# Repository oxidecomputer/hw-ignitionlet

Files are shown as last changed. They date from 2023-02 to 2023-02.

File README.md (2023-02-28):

# hw-ignitionlet
Breakout board for the ice40 FPGA with SPI PMOD interface

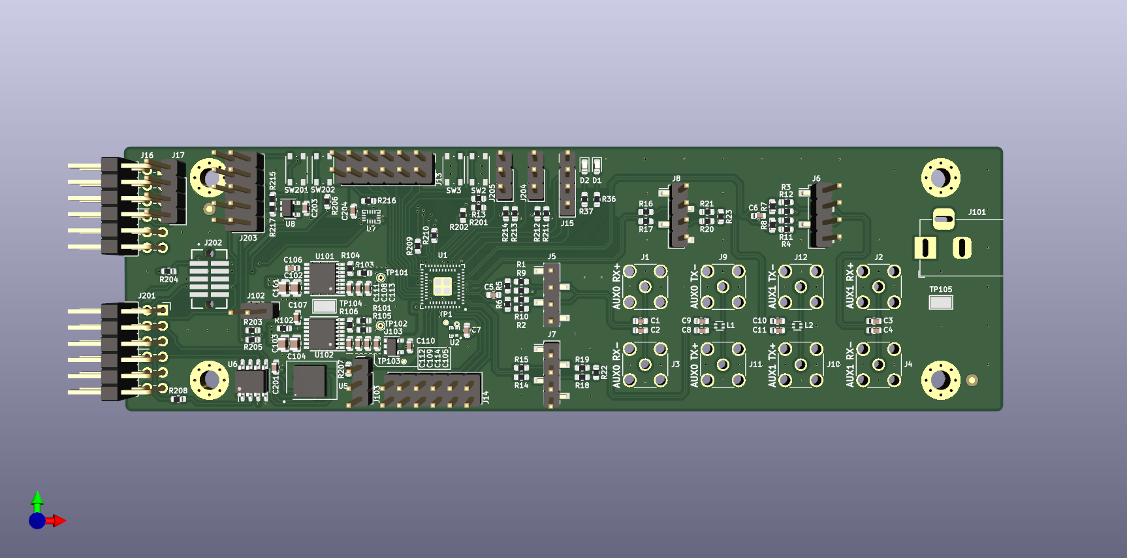
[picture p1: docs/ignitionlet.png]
ignitionlet


# Bonus boards
There is a lvds_sma_adaptor included which breaks out the LVDS pairs
with a compatible pinout to the [Lattice ECP5 Dev Kit](https://www.latticesemi.com/products/developmentboardsandkits/ecp5evaluationboard)

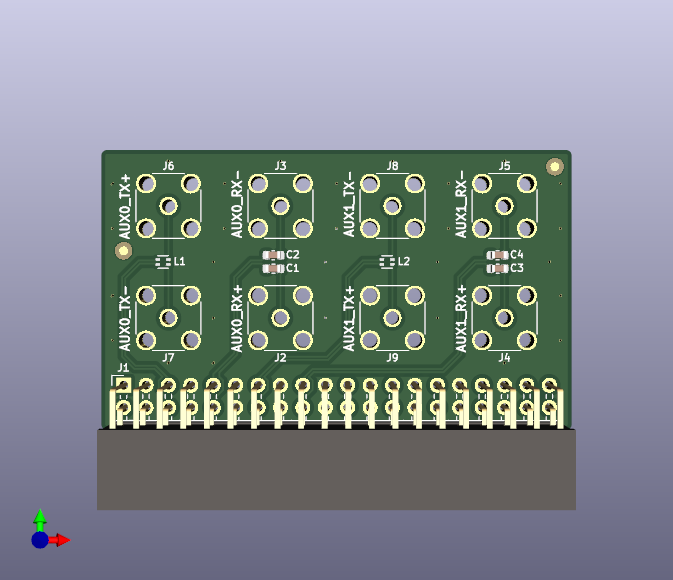
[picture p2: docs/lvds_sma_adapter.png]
lvds_board


# Status
No known required rework. See schematic notes for required
jumper settings.

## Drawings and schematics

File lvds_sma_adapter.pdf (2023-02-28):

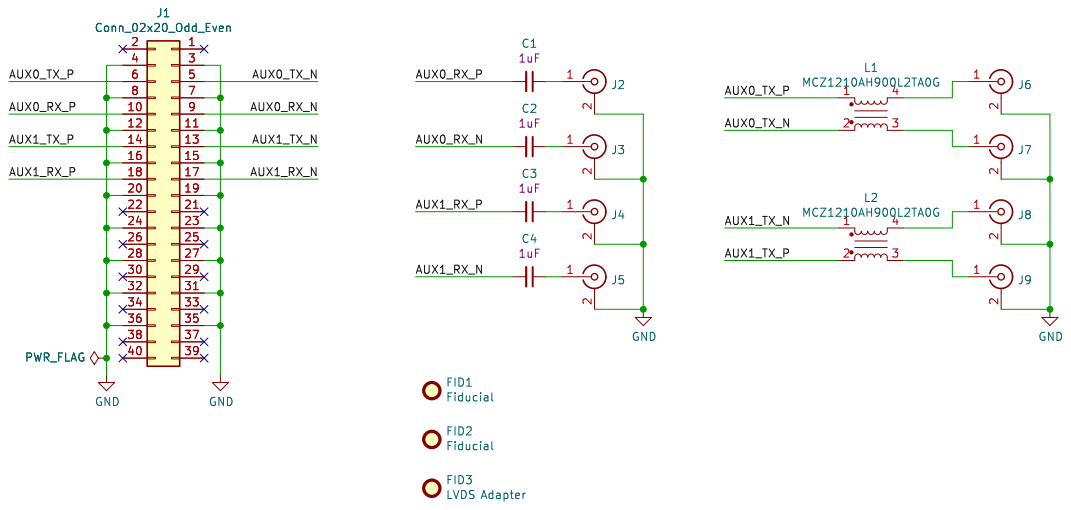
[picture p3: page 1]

Id: 1/1 Title: LVDS SMA Adapter File: lvds_sma_adapter.kicad_sch Sheet: / Oxide Computer Co. C3

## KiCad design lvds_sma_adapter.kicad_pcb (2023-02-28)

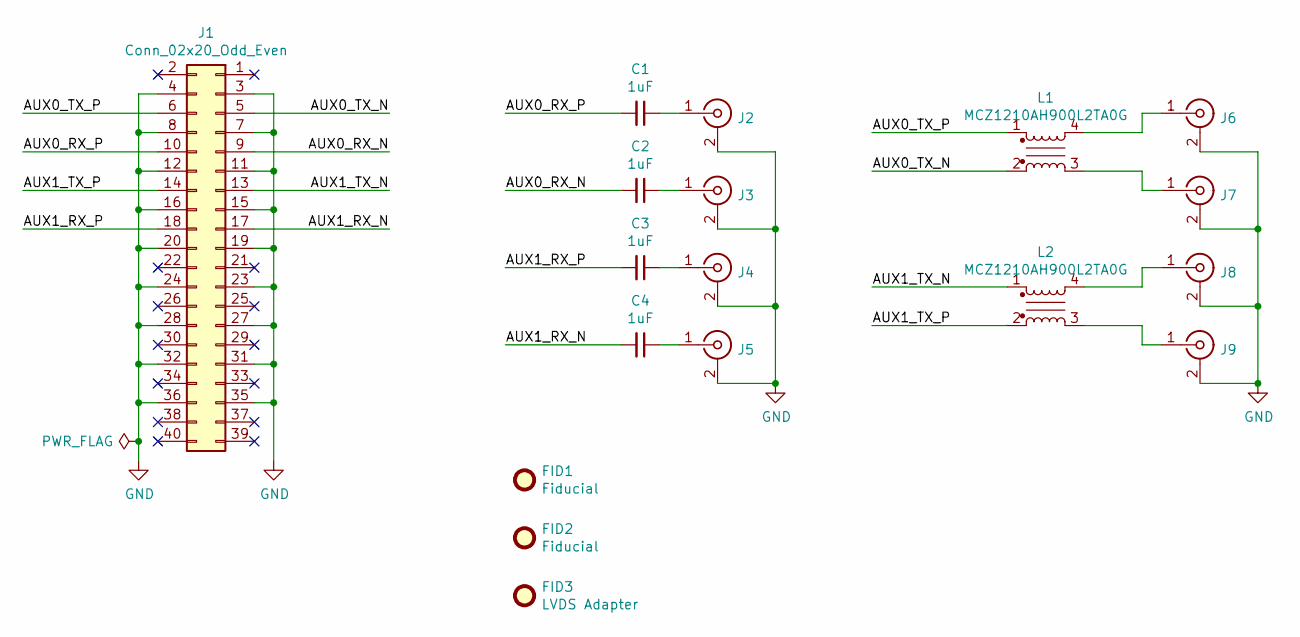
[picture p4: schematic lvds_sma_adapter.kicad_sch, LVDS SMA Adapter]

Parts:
C1, C2, C3, C4: GCM188R71E105KA64D; C_0603_1608Metric
FID1, FID2: Fiducial; Fiducial_1mm_Mask2mm
FID3: LVDS Adapter; Oxide_Board_Identifier_23x6mm
J1: Conn_02x20_Odd_Even; PinSocket_2x20_P2.54mm_Horizontal
J2, J3, J4, J5, J6, J7, J8, J9: Conn_Coaxial; SMA_Amphenol_132134-16_Vertical
L1, L2: MCZ1210AH900L2TA0G; L_Choke_MCZ1210AH

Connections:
/AUX0_RX_N: C2.2, J1.9
/AUX0_RX_P: C1.2, J1.10
/AUX0_TX_N: J1.5, L1.2
/AUX0_TX_P: J1.6, L1.1
/AUX1_RX_N: C4.2, J1.17
/AUX1_RX_P: C3.2, J1.18
/AUX1_TX_N: J1.13, L2.1
/AUX1_TX_P: J1.14, L2.2
GND: J1.3, J1.4, J1.7, J1.8, J1.11, J1.12, J1.15, J1.16, J1.19, J1.20, J1.23, J1.24, J1.27, J1.28, J1.31, J1.32, J1.35, J1.36, J2.2 (Ext), J3.2 (Ext), J4.2 (Ext), J5.2 (Ext), J6.2 (Ext), J7.2 (Ext), J8.2 (Ext), J9.2 (Ext)
unnamed: C1.1, J2.1 (In)
unnamed: C2.1, J3.1 (In)
unnamed: C3.1, J4.1 (In)
unnamed: C4.1, J5.1 (In)
unnamed: J6.1 (In), L1.4
unnamed: J7.1 (In), L1.3
unnamed: J8.1 (In), L2.4
unnamed: J9.1 (In), L2.3

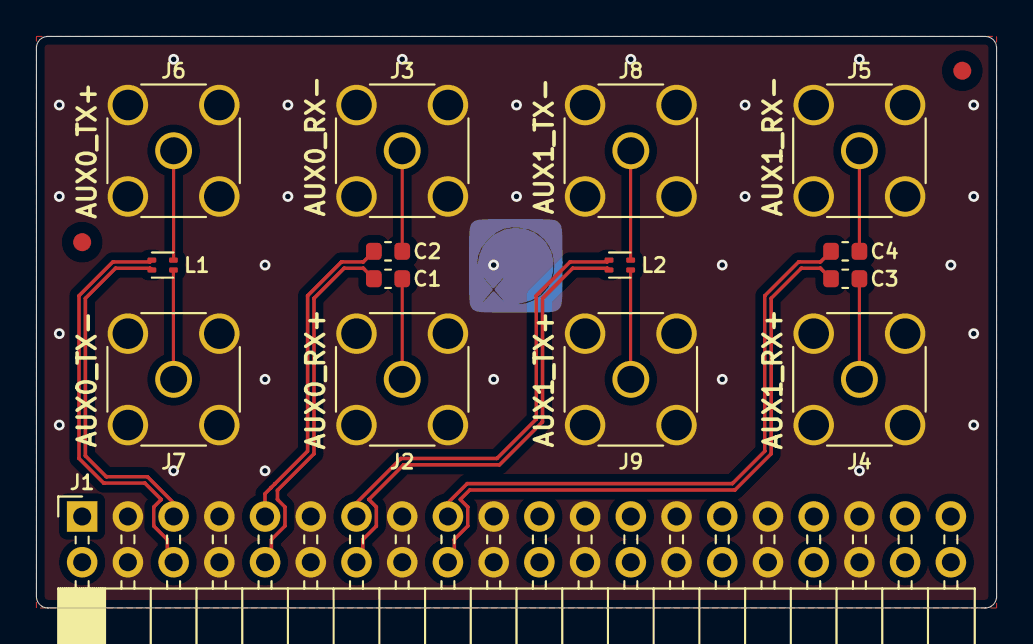
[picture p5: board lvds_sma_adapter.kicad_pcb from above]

Board: 4 copper layers, 53.3 x 31.8 mm, 18 parts (1 on the bottom side), 17 nets.

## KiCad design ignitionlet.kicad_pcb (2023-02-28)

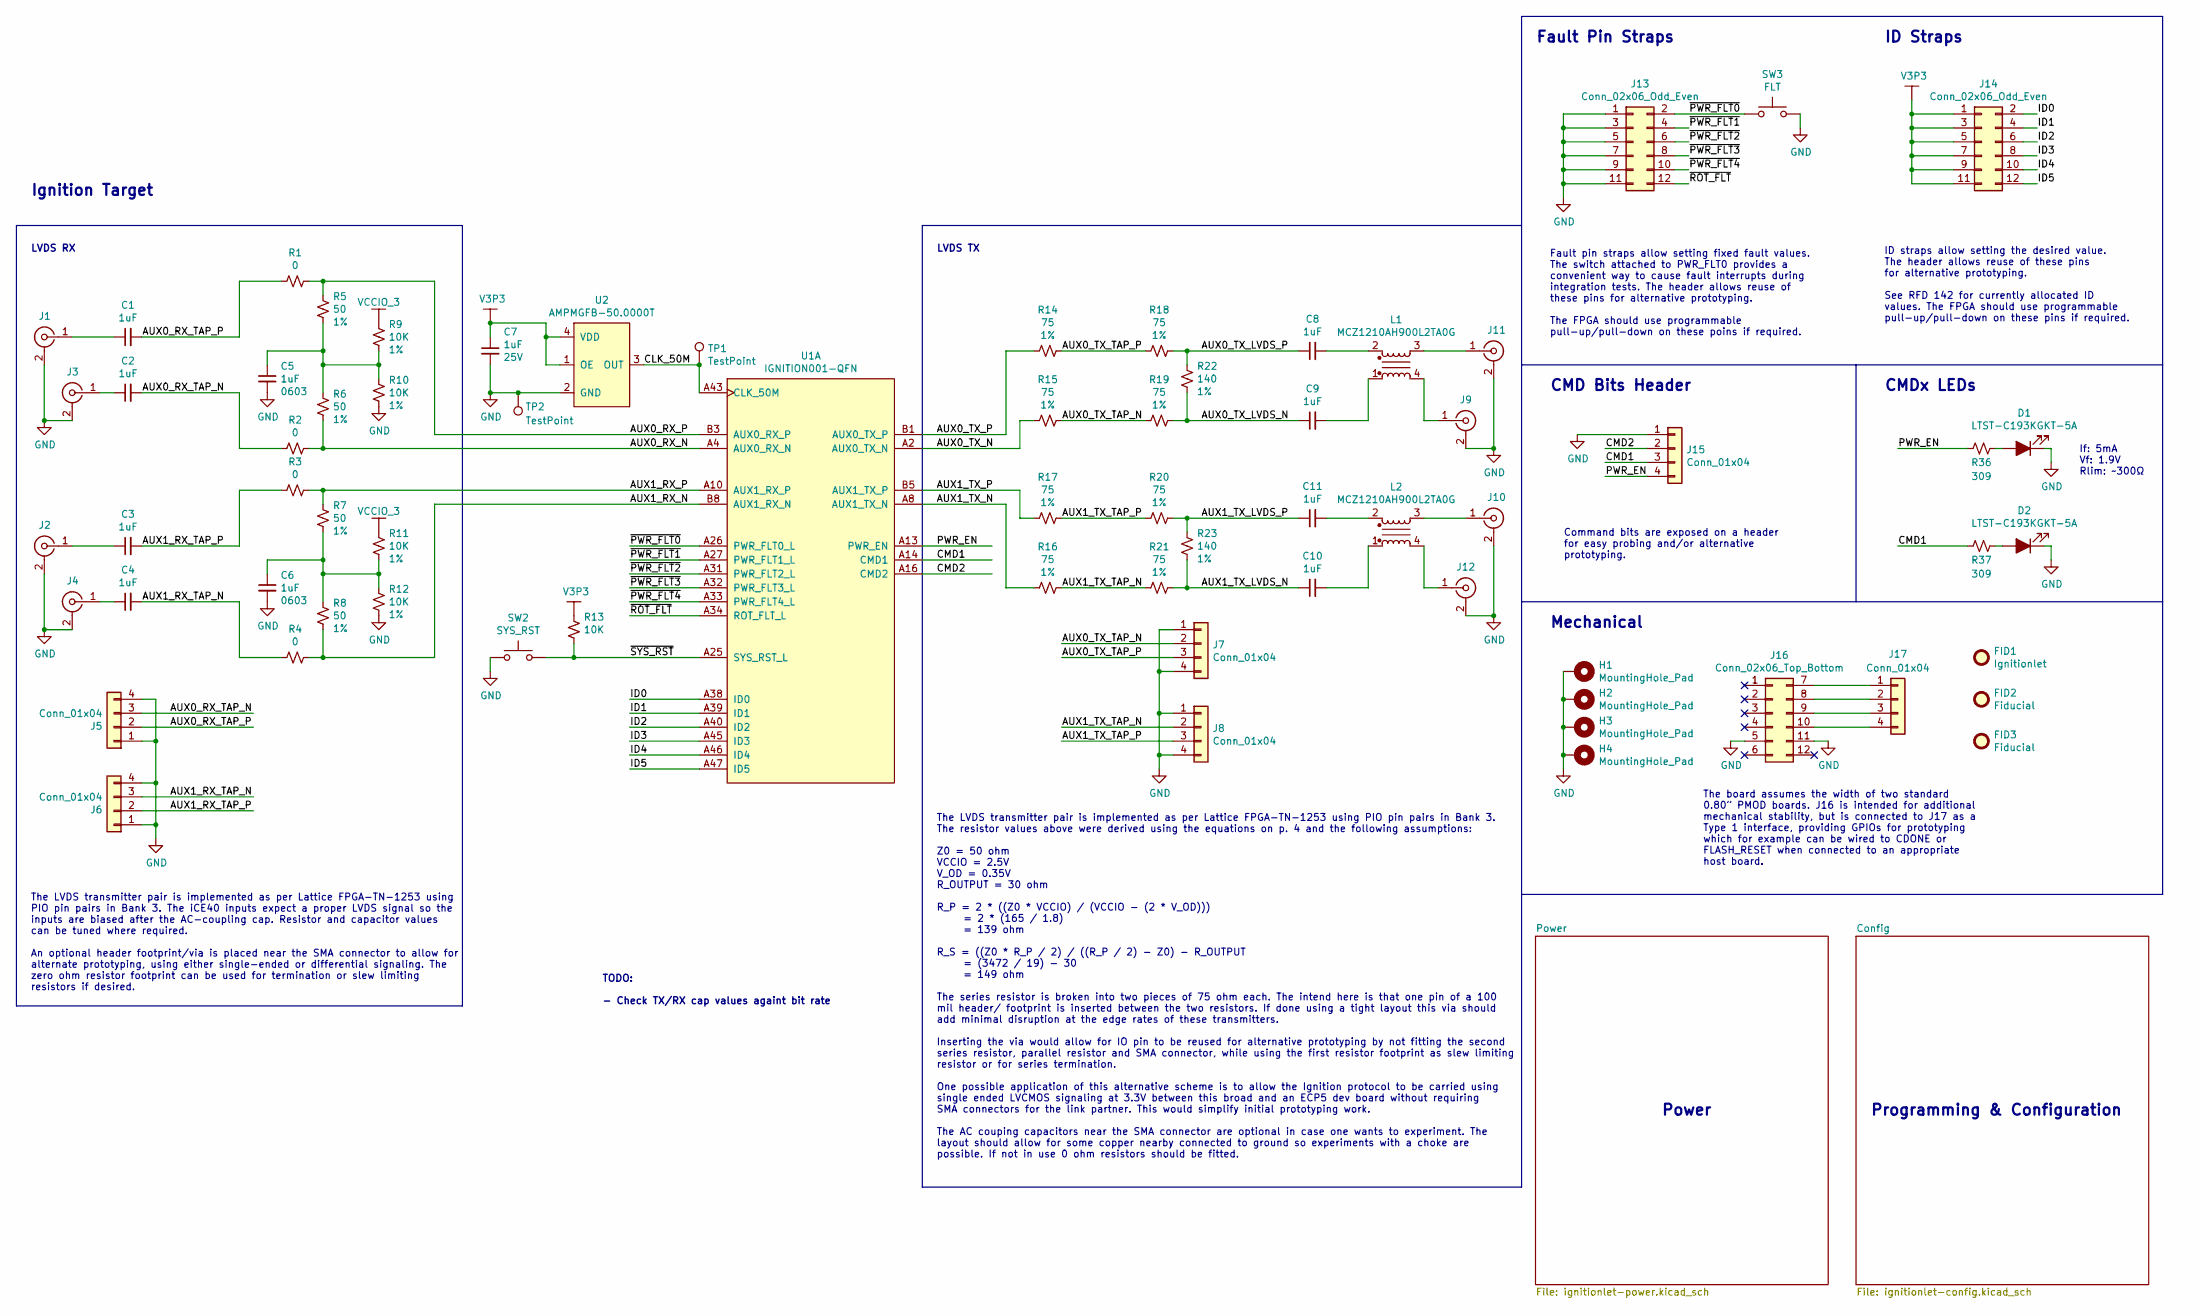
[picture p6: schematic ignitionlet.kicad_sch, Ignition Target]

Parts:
C1, C2, C3, C4, C5, C6, C7, C8, C9, C10, C11: GCM188R71E105KA64D; C_0603_1608Metric
D1, D2: LTST-C193KGKT-5A; LED_0603_1608Metric
FID1: Ignitionlet; Oxide_Board_Identifier_23x6mm_PCBWay
FID2, FID3: Fiducial; Fiducial_1mm_Mask2mm
H1, H2, H3, H4: MountingHole_Pad; MountingHole_3.2mm_M3_Pad_Via
J1, J2, J3, J4, J9, J10, J11, J12: Conn_Coaxial; SMA_Amphenol_132134-16_Vertical
J5, J6, J7, J8: Conn_01x04; PinHeader_1x04_P2.54mm_Vertical_SMD_Pin1Left
J13, J14: Conn_02x06_Odd_Even; PinHeader_2x06_P2.54mm_Vertical
J15, J17: Conn_01x04; PinHeader_1x04_P2.54mm_Vertical
J16: Conn_02x06_Top_Bottom; PMOD_12pin_peripheral_horizontal
L1, L2: MCZ1210AH900L2TA0G; L_Choke_MCZ1210AH
R1, R2, R3, R4: 0; R_0603_1608Metric; Tolerance 1%
R5, R6, R7, R8: 50; R_0603_1608Metric; Tolerance 1%
R9, R10, R11, R12, R13: 10K; R_0603_1608Metric; Tolerance 1%
R14, R15, R16, R17, R18, R19, R20, R21: 75; R_0603_1608Metric; Tolerance 1%
R22, R23: 140; R_0603_1608Metric; Tolerance 1%
R36, R37: 309; R_0603_1608Metric; Tolerance 1%
SW2: SYS_RST; PTS815
SW3: FLT; PTS815
TP1: TestPoint; TestPoint_Pad_D0.6mm
TP2: TestPoint; TestPoint_THTPad_D0.6mm_Drill0.3mm
U1: IGNITION001-QFN; Lattice_DRQFN-84-1EP_7x7mm_P0.50mm_EP3.5x3.5mm_ThermalVias
U2: AMPMGFB-50.0000T; ABRACON_VFLGA-4_1.6x1.2mm

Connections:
/AUX0_RX_N: R2.1, R6.2, U1.A4 (AUX0_RX_N)
/AUX0_RX_P: R1.1, R5.1, U1.B3 (AUX0_RX_P)
/AUX0_RX_TAP_N: C2.2, J5.3, R2.2
/AUX0_RX_TAP_P: C1.2, J5.2, R1.2
/AUX0_TX_LVDS_N: C9.1, R19.1, R22.1
/AUX0_TX_LVDS_P: C8.1, R18.1, R22.2
/AUX0_TX_N: R15.2, U1.A2 (AUX0_TX_N)
/AUX0_TX_P: R14.2, U1.B1 (AUX0_TX_P)
/AUX0_TX_TAP_N: J7.2, R15.1, R19.2
/AUX0_TX_TAP_P: J7.3, R14.1, R18.2
/AUX1_RX_N: R4.1, R8.2, U1.B8 (AUX1_RX_N)
/AUX1_RX_P: R3.1, R7.1, U1.A10 (AUX1_RX_P)
/AUX1_RX_TAP_N: C4.2, J6.3, R4.2
/AUX1_RX_TAP_P: C3.2, J6.2, R3.2
/AUX1_TX_LVDS_N: C10.1, R21.1, R23.1
/AUX1_TX_LVDS_P: C11.1, R20.1, R23.2
/AUX1_TX_N: R16.2, U1.A8 (AUX1_TX_N)
/AUX1_TX_P: R17.2, U1.B5 (AUX1_TX_P)
/AUX1_TX_TAP_N: J8.2, R16.1, R21.2
/AUX1_TX_TAP_P: J8.3, R17.1, R20.2
/CLK_50M: TP1.1, U1.A43 (CLK_50M), U2.3 (OUT)
/CMD1: J15.3, R37.2, U1.A14 (CMD1)
/CMD2: J15.2, U1.A16 (CMD2)
/ID0: J14.2, U1.A38 (ID0)
/ID1: J14.4, U1.A39 (ID1)
/ID2: J14.6, U1.A40 (ID2)
/ID3: J14.8, U1.A45 (ID3)
/ID4: J14.10, U1.A46 (ID4)
/ID5: J14.12, U1.A47 (ID5)
/PWR_EN: J15.4, R36.2, U1.A13 (PWR_EN)
/~PWR_FLT0: J13.2, SW3.1, U1.A26 (PWR_FLT0_L)
/~PWR_FLT1: J13.4, U1.A27 (PWR_FLT1_L)
/~PWR_FLT2: J13.6, U1.A31 (PWR_FLT2_L)
/~PWR_FLT3: J13.8, U1.A32 (PWR_FLT3_L)
/~PWR_FLT4: J13.10, U1.A33 (PWR_FLT4_L)
/~ROT_FLT: J13.12, U1.A34 (ROT_FLT_L)
/~SYS_RST: R13.2, SW2.2, U1.A25 (SYS_RST_L)
GND: C5.2, C6.2, C7.2, D1.1 (K), D2.1 (K), H1.1, H2.1, H3.1, H4.1, J1.2 (Ext), J2.2 (Ext), J3.2 (Ext), J4.2 (Ext), J5.1, J5.4, J6.1, J6.4, J7.1, J7.4, J8.1, J8.4, J9.2 (Ext), J10.2 (Ext), J11.2 (Ext), J12.2 (Ext), J13.1, J13.3, J13.5, J13.7, J13.9, J13.11, J15.1, J16.5, J16.11, R10.2, R12.2, SW2.1, SW3.2, TP2.1, U2.2 (GND); also elsewhere on the board
unnamed: C1.1, J1.1 (In)
unnamed: C2.1, J3.1 (In)
unnamed: C3.1, J2.1 (In)
unnamed: C4.1, J4.1 (In)
unnamed: C5.1, R5.2, R6.1, R9.2, R10.1
unnamed: C6.1, R7.2, R8.1, R11.2, R12.1
unnamed: C8.2, L1.2
unnamed: C9.2, L1.1
unnamed: C10.2, L2.1
unnamed: C11.2, L2.2
unnamed: D1.2 (A), R36.1
unnamed: D2.2 (A), R37.1
unnamed: J9.1 (In), L1.4
unnamed: J10.1 (In), L2.3
unnamed: J11.1 (In), L1.3
unnamed: J12.1 (In), L2.4
unnamed: J16.7, J17.1
unnamed: J16.8, J17.2
unnamed: J16.9, J17.3
unnamed: J16.10, J17.4
V3P3: C7.1, J14.1, J14.3, J14.5, J14.7, J14.9, J14.11, R13.1, U2.1 (OE), U2.4 (VDD); also elsewhere on the board
VCCIO_3: R9.1, R11.1; also elsewhere on the board

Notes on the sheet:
CMDx LEDs
The board assumes the width of two standard 0.80” PMOD boards. J16 is intended for additional mechanical stability, but is connected to J17 as a Type 1 interface, providing GPIOs for prototyping which for example can be wired to CDONE or FLASH_RESET when connected to an appropriate host board.
LVDS TX
Ignition Target
Mechanical
Fault Pin Straps
Command bits are exposed on a header for easy probing and/or alternative prototyping.
The LVDS transmitter pair is implemented as per Lattice FPGA-TN-1253 using PIO pin pairs in Bank 3. The resistor values above were derived using the equations on p. 4 and the following assumptions: Z0 = 50 ohm VCCIO = 2.5V V_OD = 0.35V R_OUTPUT = 30 ohm R_P = 2 * ((Z0 * VCCIO) / (VCCIO - (2 * V_OD)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
LVDS RX
ID Straps
CMD Bits Header
Fault pin straps allow setting fixed fault values. The switch attached to PWR_FLT0 provides a convenient way to cause fault interrupts during integration tests. The header allows reuse of these pins for alternative prototyping. The FPGA should use programmable pull-up/pull-down on these poins if re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
Programming & Configuration
The LVDS transmitter pair is implemented as per Lattice FPGA-TN-1253 using PIO pin pairs in Bank 3. The iCE40 inputs expect a proper LVDS signal so the inputs are biased after the AC-coupling cap. Resistor and capacitor values can be tuned where required. An optional header footprint/via is placed 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
ID straps allow setting the desired value. The header allows reuse of these pins for alternative prototyping. See RFD 142 for currently allocated ID values. The FPGA should use programmable pull-up/pull-down on these pins if required.
If: 5mA Vf: 1.9V Rlim: ~300Ω
Power
TODO: - Check TX/RX cap values againt bit rate

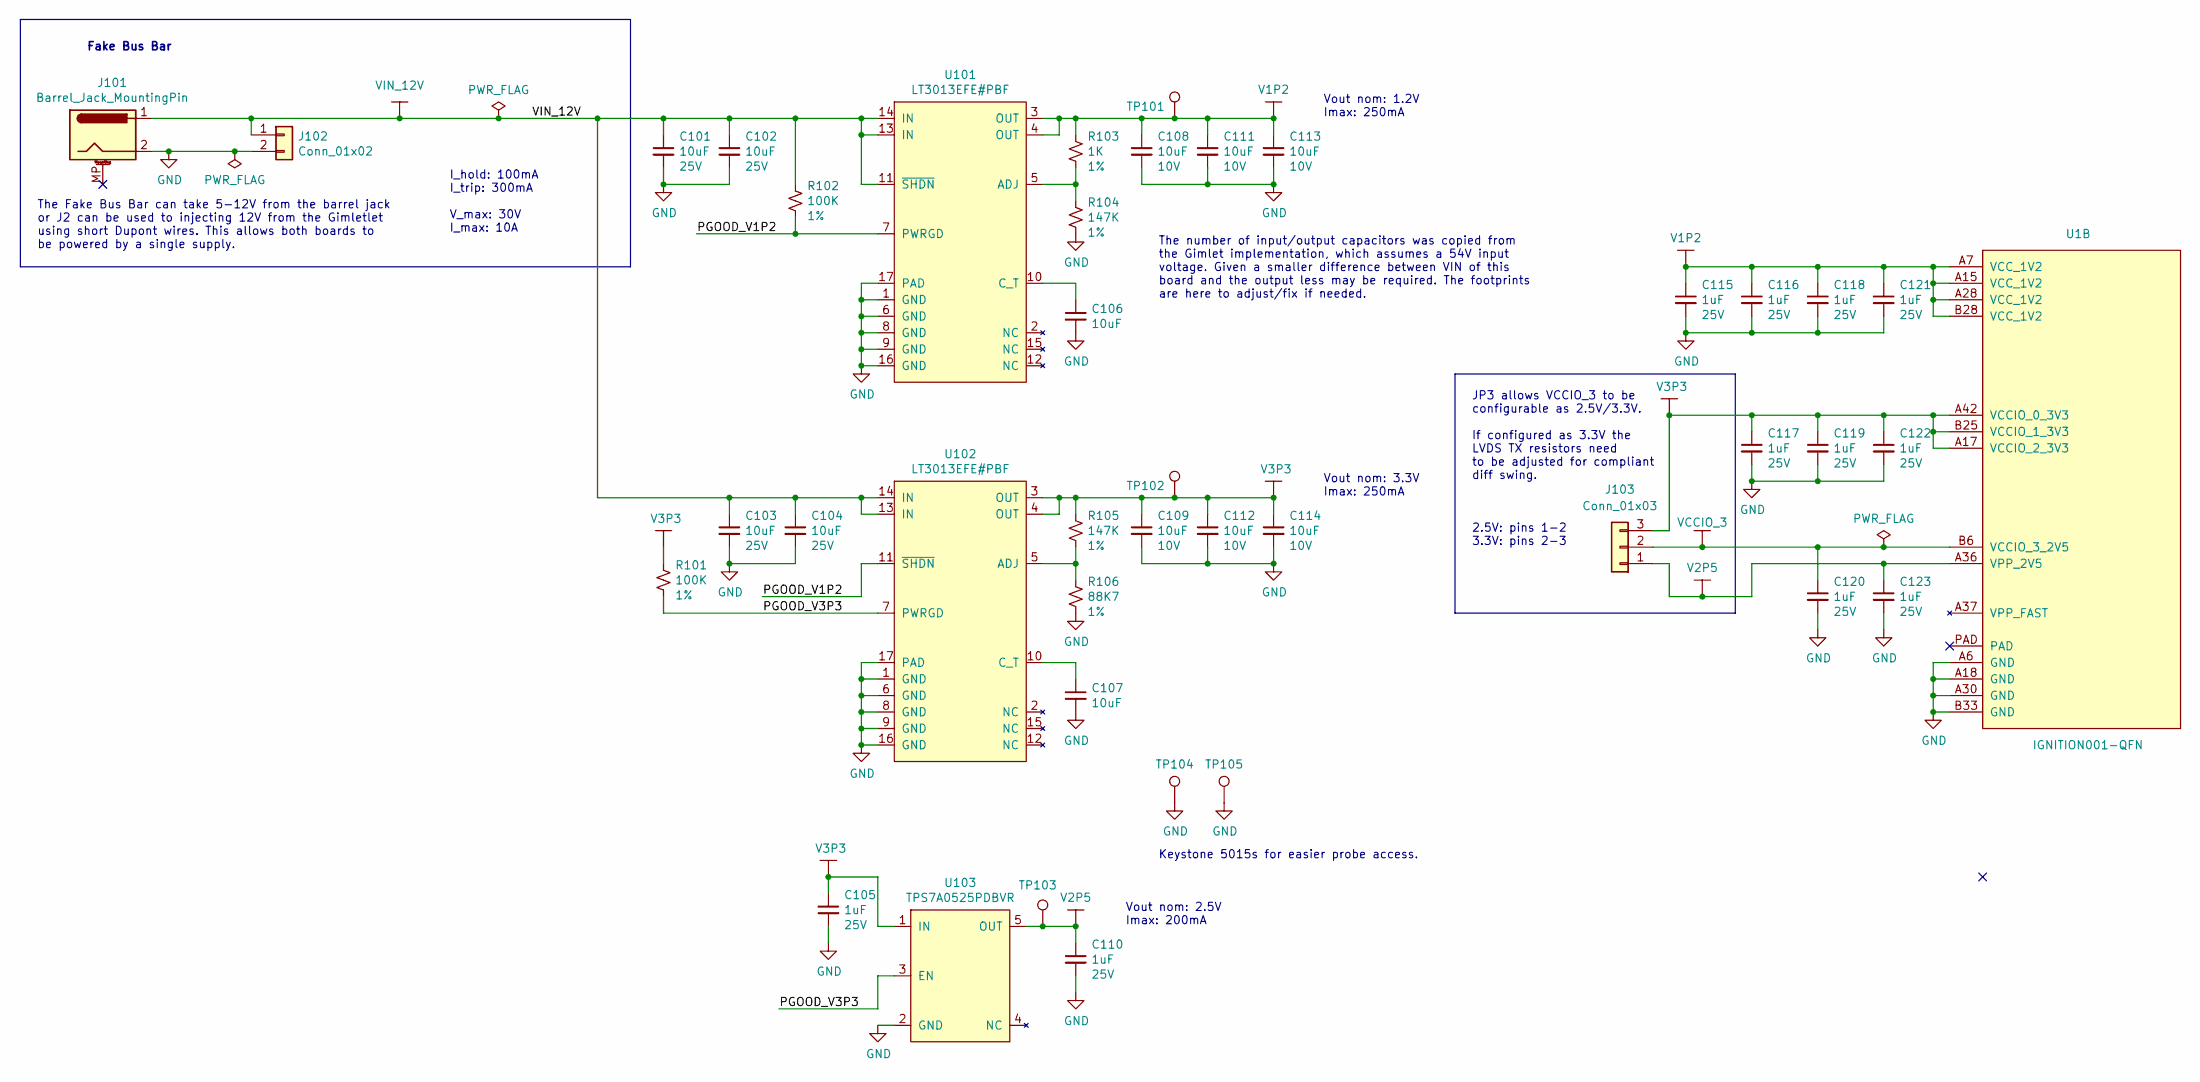
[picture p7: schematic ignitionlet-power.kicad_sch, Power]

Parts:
C101, C102, C103, C104: GRM21BR61E106KA73K; C_0805_2012Metric; Voltage 25V
C105, C110, C115, C116, C117, C118, C119, C120, C121, C122, C123: GCM188R71E105KA64D; C_0603_1608Metric
C106, C107: C0603C106M8PACTU; C_0603_1608Metric
C108, C109, C111, C112, C113, C114: C0603C106M8PACTU; C_0603_1608Metric; Voltage 10V
J101: Barrel_Jack_MountingPin; BarrelJack_Horizontal
J102: Conn_01x02; PinHeader_1x02_P2.54mm_Vertical
J103: Conn_01x03; PinHeader_1x03_P2.54mm_Vertical
R101, R102: 100K; R_0603_1608Metric; Tolerance 1%
R103: 1K; R_0603_1608Metric; Tolerance 1%
R104, R105: 147K; R_0603_1608Metric; Tolerance 1%
R106: 88K7; R_0603_1608Metric; Tolerance 1%
TP101, TP102: TestPoint; TestPoint_THTPad_D1.0mm_Drill0.5mm
TP103: TestPoint; TestPoint_Pad_D0.6mm
TP104, TP105: TestPoint; TestPoint_Keystone_5015_Micro-Minature
U1: IGNITION001-QFN
U101, U102: LT3013EFE#PBF; TSSOP-16-1EP_4.4x5mm_P0.65mm
U103: TPS7A0525PDBVR; SOT-23-5

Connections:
/Power/PGOOD_V1P2: R102.2, U101.7 (PWRGD), U102.11 (~SHDN)
/Power/PGOOD_V3P3: R101.2, U102.7 (PWRGD), U103.3 (EN)
GND: C101.2, C102.2, C103.2, C104.2, C105.2, C106.2, C107.2, C108.2, C109.2, C110.2, C111.2, C112.2, C113.2, C114.2, C115.2, C116.2, C117.2, C118.2, C119.2, C120.2, C121.2, C122.2, C123.2, J101.2, J102.2, R104.2, R106.2, TP104.1, TP105.1, U1.A6 (GND), U1.A18 (GND), U1.A30 (GND), U1.B33 (GND), U101.1 (GND), U101.6 (GND), U101.8 (GND), U101.9 (GND), U101.16 (GND), U101.17 (PAD), U102.1 (GND), U102.6 (GND), U102.8 (GND), U102.9 (GND), U102.16 (GND), U102.17 (PAD), U103.2 (GND); also elsewhere on the board
unnamed: C106.1, U101.10 (C_T)
unnamed: C107.1, U102.10 (C_T)
unnamed: R103.2, R104.1, U101.5 (ADJ)
unnamed: R105.2, R106.1, U102.5 (ADJ)
V1P2: C108.1, C111.1, C113.1, C115.1, C116.1, C118.1, C121.1, R103.1, TP101.1, U1.A7 (VCC_1V2), U1.A15 (VCC_1V2), U1.A28 (VCC_1V2), U1.B28 (VCC_1V2), U101.3 (OUT), U101.4 (OUT)
V2P5: C110.1, C123.1, J103.1, TP103.1, U1.A36 (VPP_2V5), U103.5 (OUT)
V3P3: C105.1, C109.1, C112.1, C114.1, C117.1, C119.1, C122.1, J103.3, R101.1, R105.1, TP102.1, U1.A17 (VCCIO_2_3V3), U1.A42 (VCCIO_0_3V3), U1.B25 (VCCIO_1_3V3), U102.3 (OUT), U102.4 (OUT), U103.1 (IN); also elsewhere on the board
VCCIO_3: C120.1, J103.2, U1.B6 (VCCIO_3_2V5); also elsewhere on the board
VIN_12V: C101.1, C102.1, C103.1, C104.1, J101.1, J102.1, R102.1, U101.11 (~SHDN), U101.13 (IN), U101.14 (IN), U102.13 (IN), U102.14 (IN)

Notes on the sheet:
Vout nom: 2.5V Imax: 200mA
Fake Bus Bar
The Fake Bus Bar can take 5-12V from the barrel jack or J2 can be used to injecting 12V from the Gimletlet using short Dupont wires. This allows both boards to be powered by a single supply.
Keystone 5015s for easier probe access.
I_hold: 100mA I_trip: 300mA V_max: 30V I_max: 10A
The number of input/output capacitors was copied from the Gimlet implementation, which assumes a 54V input voltage. Given a smaller difference between VIN of this board and the output less may be required. The footprints are here to adjust/fix if needed.
2.5V: pins 1-2 3.3V: pins 2-3
Vout nom: 1.2V Imax: 250mA
JP3 allows VCCIO_3 to be configurable as 2.5V/3.3V. If configured as 3.3V the LVDS TX resistors need to be adjusted for compliant diff swing.
Vout nom: 3.3V Imax: 250mA

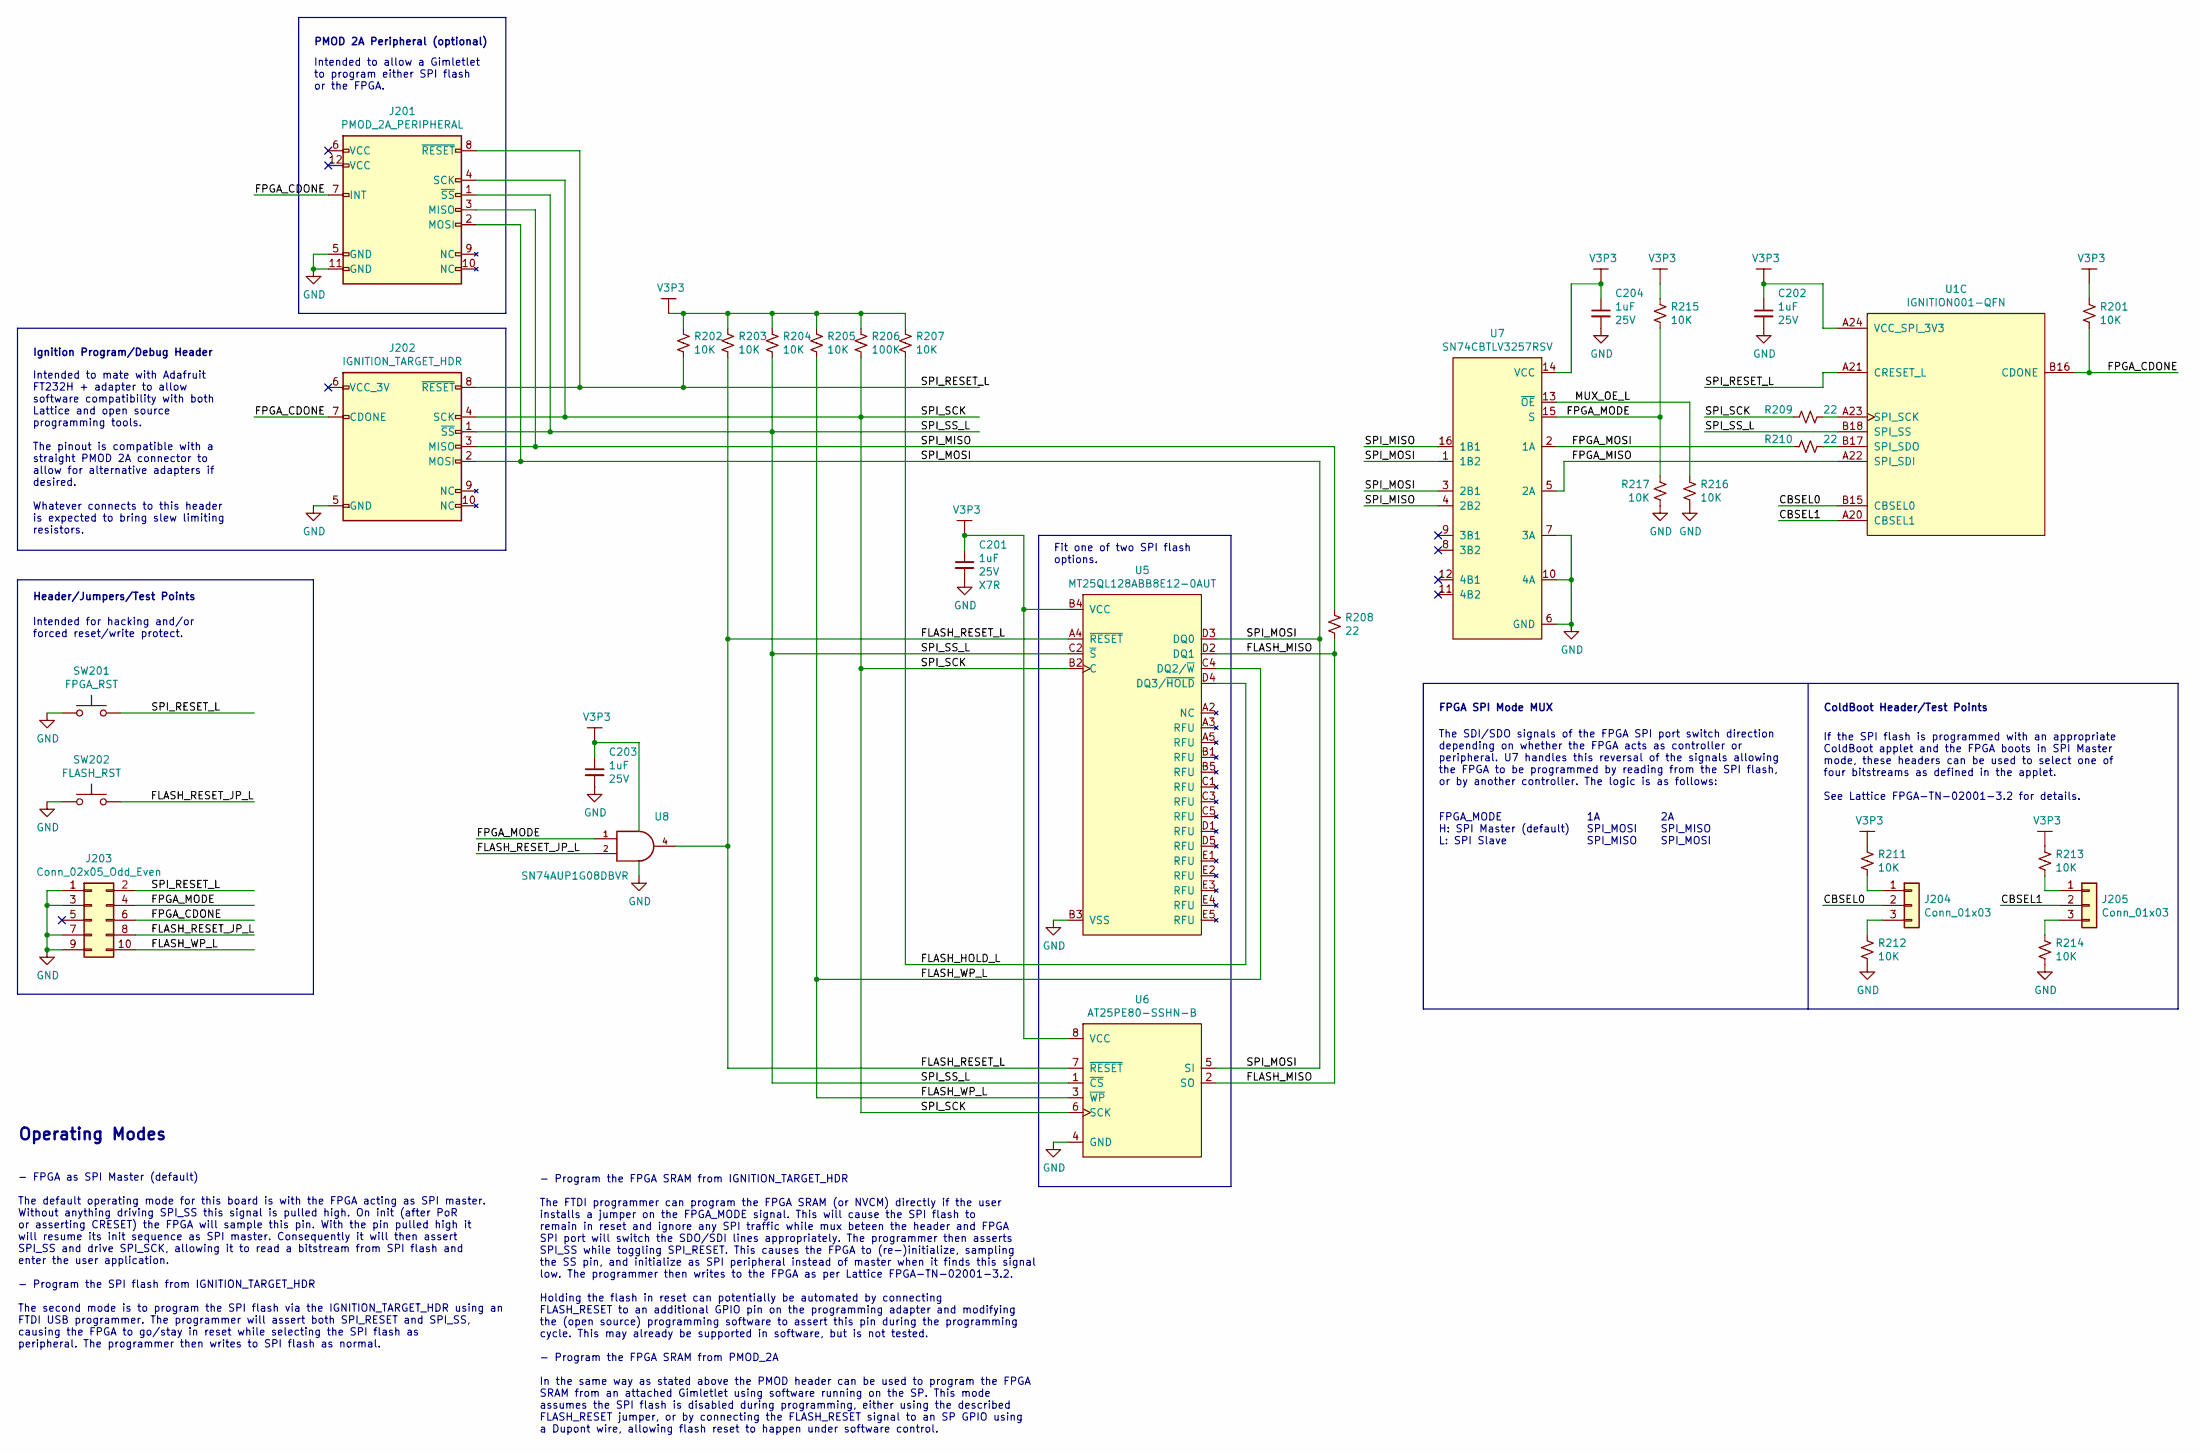
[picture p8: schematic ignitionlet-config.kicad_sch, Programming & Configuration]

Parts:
C201, C202, C203, C204: GCM188R71E105KA64D; C_0603_1608Metric
J201: PMOD_2A_PERIPHERAL; PMOD_12pin_peripheral_horizontal
J202: IGNITION_TARGET_HDR; TFC-105-02-F-D-A-K
J203: Conn_02x05_Odd_Even; PinHeader_2x05_P2.54mm_Vertical
J204, J205: Conn_01x03; PinHeader_1x03_P2.54mm_Vertical
R201, R202, R203, R204, R205, R207, R211, R212, R213, R214, R215, R216, R217: 10K; R_0603_1608Metric; Tolerance 1%
R206: 100K; R_0603_1608Metric; Tolerance 1%
R208, R209, R210: 22; R_0603_1608Metric; Tolerance 1%
SW201: FPGA_RST; PTS815
SW202: FLASH_RST; PTS815
U1: IGNITION001-QFN
U5: MT25QL128ABB8E12-0AUT; T-PBGA-24_6x8mm_Layout5x5_P1.0mm
U6: AT25PE80-SSHN-B; SOIC-8_3.9x4.9mm_P1.27mm
U7: SN74CBTLV3257RSV; Texas_RSV_S-UQFN-16_2.4x1.6mm
U8: SN74AUP1G08DBVR; SOT-23-5

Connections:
/Config/CBSEL0: J204.2, U1.B15 (CBSEL0)
/Config/CBSEL1: J205.2, U1.A20 (CBSEL1)
/Config/FLASH_HOLD_L: R207.1, U5.D4 (DQ3/~HOLD)
/Config/FLASH_MISO: R208.1, U5.D2 (DQ1), U6.2 (SO)
/Config/FLASH_RESET_JP_L: J203.8, SW202.2, U8.2
/Config/FLASH_RESET_L: R203.1, U5.A4 (~RESET), U6.7 (~RESET), U8.4
/Config/FLASH_WP_L: J203.10, R205.1, U5.C4 (DQ2/~W), U6.3 (~WP)
/Config/FPGA_CDONE: J201.7 (INT), J202.7 (CDONE), J203.6, R201.1, U1.B16 (CDONE)
/Config/FPGA_MISO: U1.A22 (SPI_SDI), U7.5 (2A)
/Config/FPGA_MODE: J203.4, R215.1, R217.2, U7.15 (S), U8.1
/Config/FPGA_MOSI: R210.2, U7.2 (1A)
/Config/MUX_OE_L: R216.2, U7.13 (~OE)
/Config/SPI_MISO: J201.3 (MISO), J202.3 (MISO), R208.2, U7.4 (2B2), U7.16 (1B1)
/Config/SPI_MOSI: J201.2 (MOSI), J202.2 (MOSI), U5.D3 (DQ0), U6.5 (SI), U7.1 (1B2), U7.3 (2B1)
/Config/SPI_RESET_L: J201.8 (~RESET), J202.8 (~RESET), J203.2, R202.1, SW201.2, U1.A21 (CRESET_L)
/Config/SPI_SCK: J201.4 (SCK), J202.4 (SCK), R206.1, R209.2, U5.B2 (C), U6.6 (SCK)
/Config/SPI_SS_L: J201.1 (~SS), J202.1 (~SS), R204.1, U1.B18 (SPI_SS), U5.C2 (~S), U6.1 (~CS)
GND: C201.2, C202.2, C203.2, C204.2, J201.5 (GND), J201.11 (GND), J202.5 (GND), J203.1, J203.3, J203.7, J203.9, R212.1, R214.1, R216.1, R217.1, SW201.1, SW202.1, U5.B3 (VSS), U6.4 (GND), U7.6 (GND), U7.7 (3A), U7.10 (4A), U8.3 (GND); also elsewhere on the board
unnamed: J204.1, R211.1
unnamed: J204.3, R212.2
unnamed: J205.1, R213.1
unnamed: J205.3, R214.2
unnamed: R209.1, U1.A23 (SPI_SCK)
unnamed: R210.1, U1.B17 (SPI_SDO)
V3P3: C201.1, C202.1, C203.1, C204.1, R201.2, R202.2, R203.2, R204.2, R205.2, R206.2, R207.2, R211.2, R213.2, R215.2, U1.A24 (VCC_SPI_3V3), U5.B4 (VCC), U6.8 (VCC), U7.14 (VCC), U8.5 (VCC); also elsewhere on the board

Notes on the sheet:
Ignition Program/Debug Header
The SDI/SDO signals of the FPGA SPI port switch direction depending on whether the FPGA acts as controller or peripheral. U7 handles this reversal of the signals allowing the FPGA to be programmed by reading from the SPI flash, or by another controller. The logic is as follows:
FPGA_MODE H: SPI Master (default) L: SPI Slave
Fit one of two SPI flash options.
Intended to allow a Gimletlet to program either SPI flash or the FPGA.
Operating Modes
ColdBoot Header/Test Points
Intended for hacking and/or forced reset/write protect.
- Program the FPGA SRAM from IGNITION_TARGET_HDR The FTDI programmer can program the FPGA SRAM (or NVCM) directly if the user installs a jumper on the FPGA_MODE signal. This will cause the SPI flash to remain in reset and ignore any SPI traffic while mux beteen the header and FPGA SPI port will swi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
Header/Jumpers/Test Points
2A SPI_MISO SPI_MOSI
PMOD 2A Peripheral (optional)
Intended to mate with Adafruit FT232H + adapter to allow software compatibility with both Lattice and open source programming tools. The pinout is compatible with a straight PMOD 2A connector to allow for alternative adapters if desired. Whatever connects to this header is expected to bring slew li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
If the SPI flash is programmed with an appropriate ColdBoot applet and the FPGA boots in SPI Master mode, these headers can be used to select one of four bitstreams as defined in the applet. See Lattice FPGA-TN-02001-3.2 for details.
1A SPI_MOSI SPI_MISO
FPGA SPI Mode MUX
- FPGA as SPI Master (default) The default operating mode for this board is with the FPGA acting as SPI master. Without anything driving SPI_SS this signal is pulled high. On init (after PoR or asserting CRESET) the FPGA will sample this pin. With the pin pulled high it will resume its init sequenc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

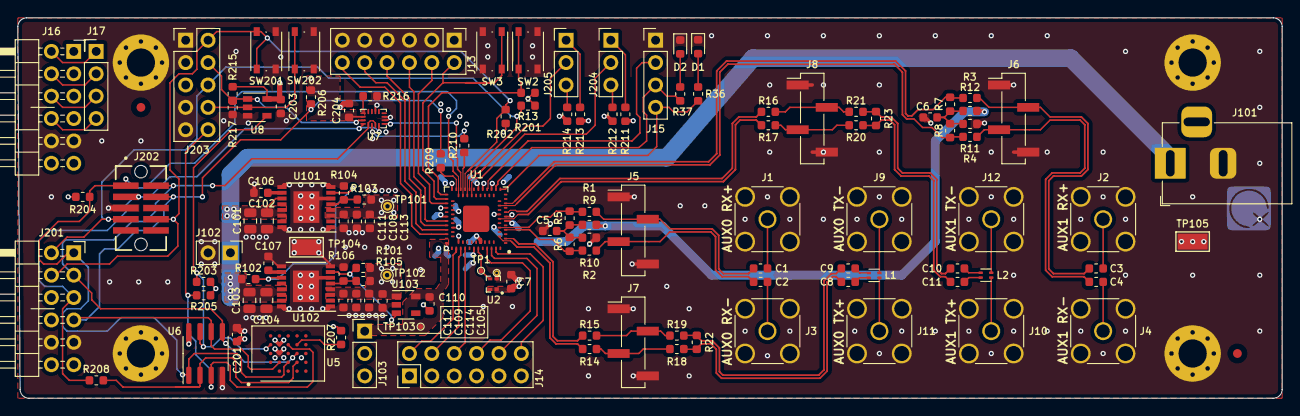
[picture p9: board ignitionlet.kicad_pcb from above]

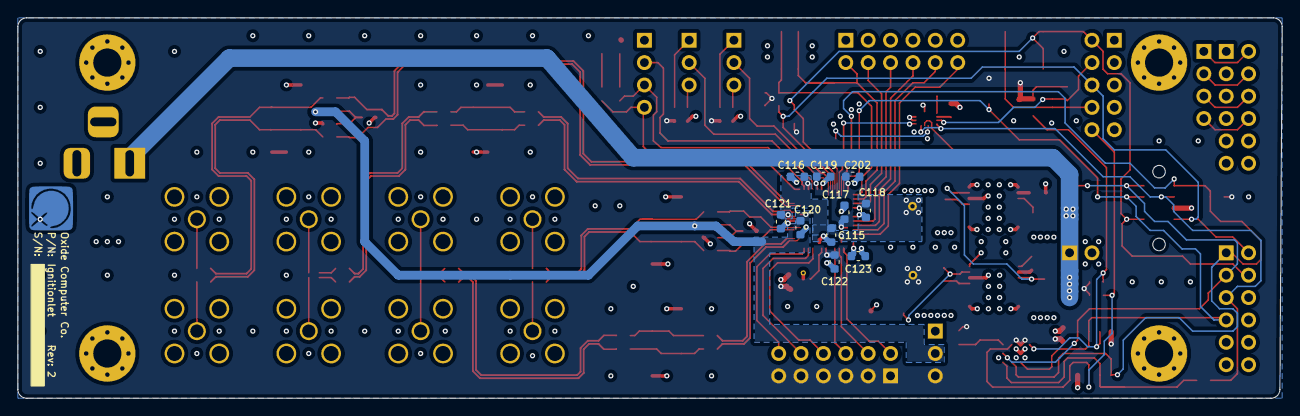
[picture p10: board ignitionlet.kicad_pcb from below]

Board: 4 copper layers, 143.5 x 43.2 mm, 142 parts (11 on the bottom side), 92 nets.
